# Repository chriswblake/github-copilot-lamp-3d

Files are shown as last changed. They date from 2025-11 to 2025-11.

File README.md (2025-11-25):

# GitHub Copilot Lamp 3D

Various lamp parts on a table

A fun and playful lamp to match the energy of GitHub Copilot. It's 3D printable and fairly easy to assemble!

- WiFi Connected
- Powered by [WLED](https://kno.wled.ge/)
- Compatibile with [Home Assistant](https://www.home-assistant.io/)

#### Other Fun GitHub Lamps

- [Copilot Lamp (2D)](https://github.com/chriswblake/github-copilot-lamp)
- [Octolamp](https://github.com/martinwoodward/octolamp)

## Build your own 🤓

That's cool and all, but how do I make one?!  
Check out the [build your own](docs/build-your-own.md) page for a step-by-step guide. 🧑‍🚀

## How to Use

If you received your lamp prebuilt, is has already been configured and is ready to use. Simply plug it in with a USB cable and power brick with at least 1 amp. The lamp will turn on with an "rainbow" like green effect.

### Connect with the App

1. Ensure you are on the same WiFi network.

2. Download the WLED app.
   - [iOS App](https://apps.apple.com/us/app/wled/id1475695033)
   - [Android App](https://play.google.com/store/apps/details?id=com.aircoookie.WLED)
   - The lamp can also be accessed with web browser by navigating to http://copilot-lamp-3d.local.
3. Open the app and the lamp should automatically be discovered.

### Predefined Segments, Presets, and Playlists

There are 5 predefined segments for the face, eyes, and goggles. There are also various example presets that use them to easily adjust the look of Copilot.

Below are some examples of changing the eye color, eye position, and applying animations to the face.

<div>
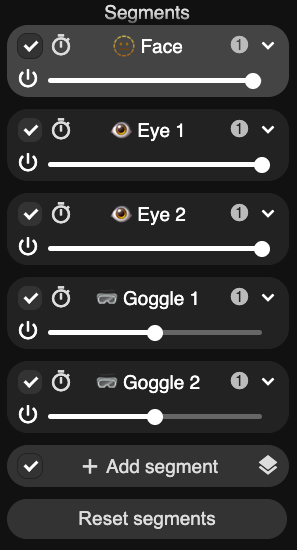
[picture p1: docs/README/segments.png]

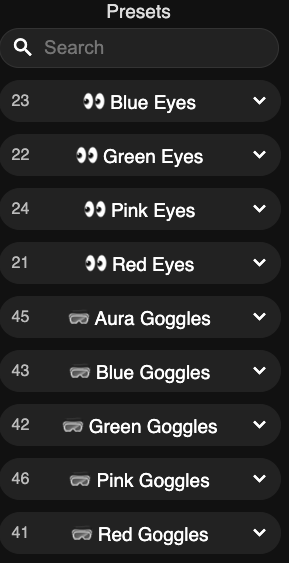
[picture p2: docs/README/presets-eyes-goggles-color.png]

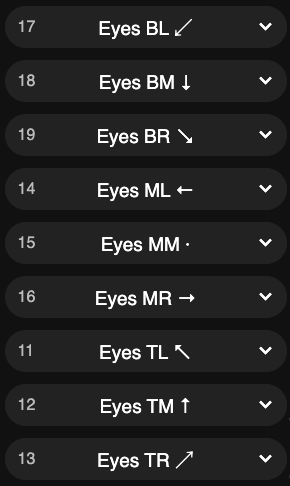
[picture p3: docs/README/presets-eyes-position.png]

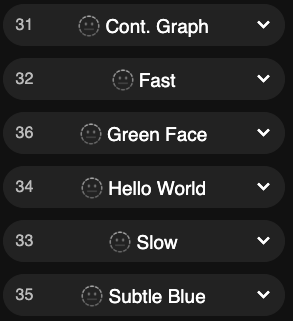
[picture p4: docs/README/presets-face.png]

</div>

> [!TIP]
> You can also do scrolling text! Check out the "Hello World" example.

### Connect to WiFi

Want full control over your lamp? Connect it to your WiFi network! (2.4ghz only)
If not connected to an existing wifi, it will broadcast a tempory wifi network for setup.

1. On your phone or computer, search for the wifi network `copilot-lamp-3d` and connect to it.
   - Default password is `copilot-lamp-3d` or `wled1234`.
1. Wait a moment and a temporary login-style web browser will appear. If no browser appears, open a web browser navigate to http://copilot-lamp-3d.local.
1. In the top right, click the **Config** gear icon to open the settings menu.
1. Select **WiFi Setup**.
1. Enter you home's wifi name and password. Click **Save & Connect**. Wait a moment for the lamp to restart.
1. Reconnect your phone or computer to your home wifi.

<div>
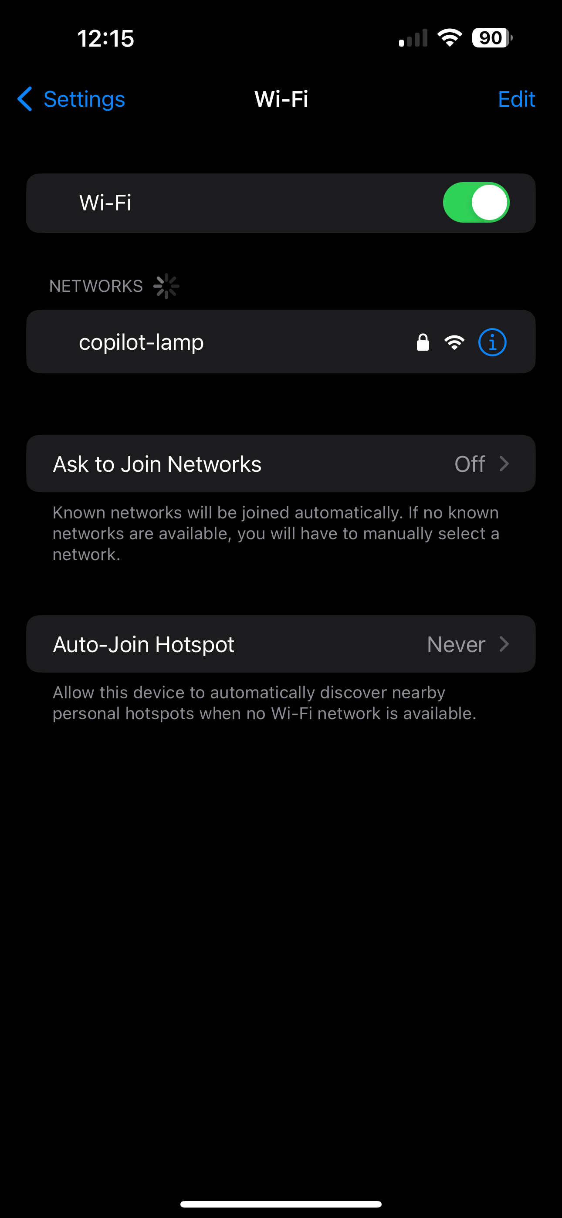
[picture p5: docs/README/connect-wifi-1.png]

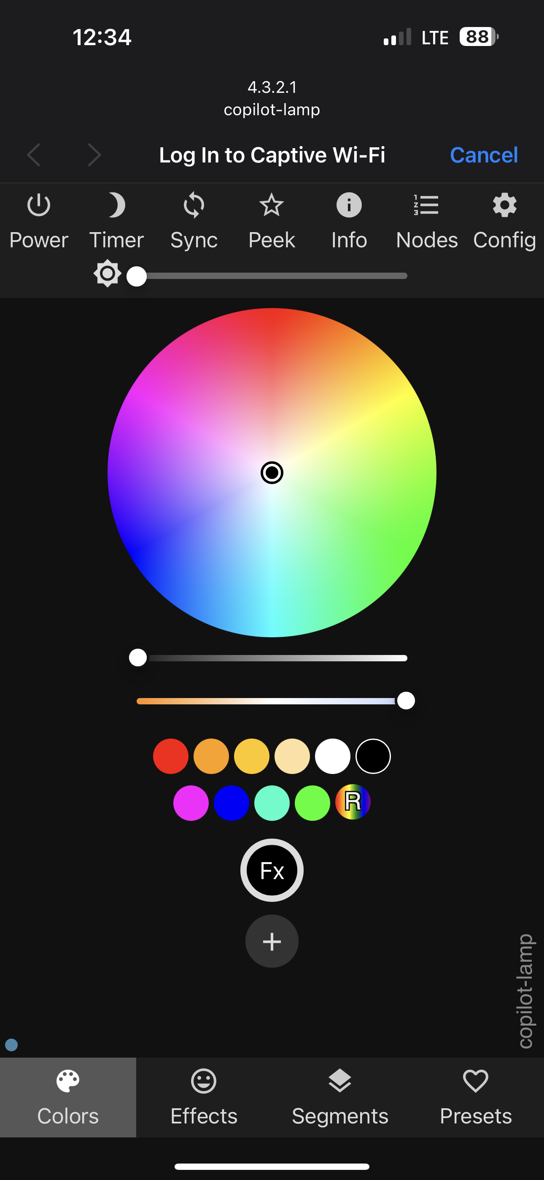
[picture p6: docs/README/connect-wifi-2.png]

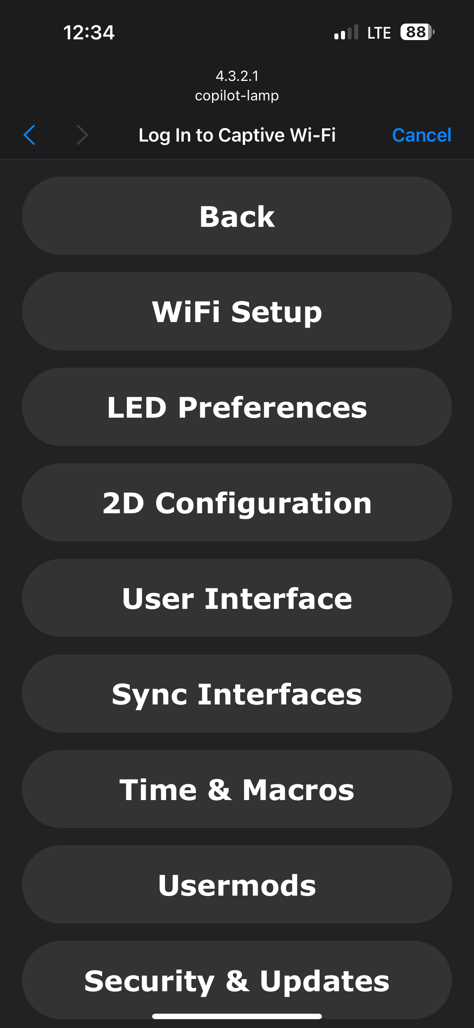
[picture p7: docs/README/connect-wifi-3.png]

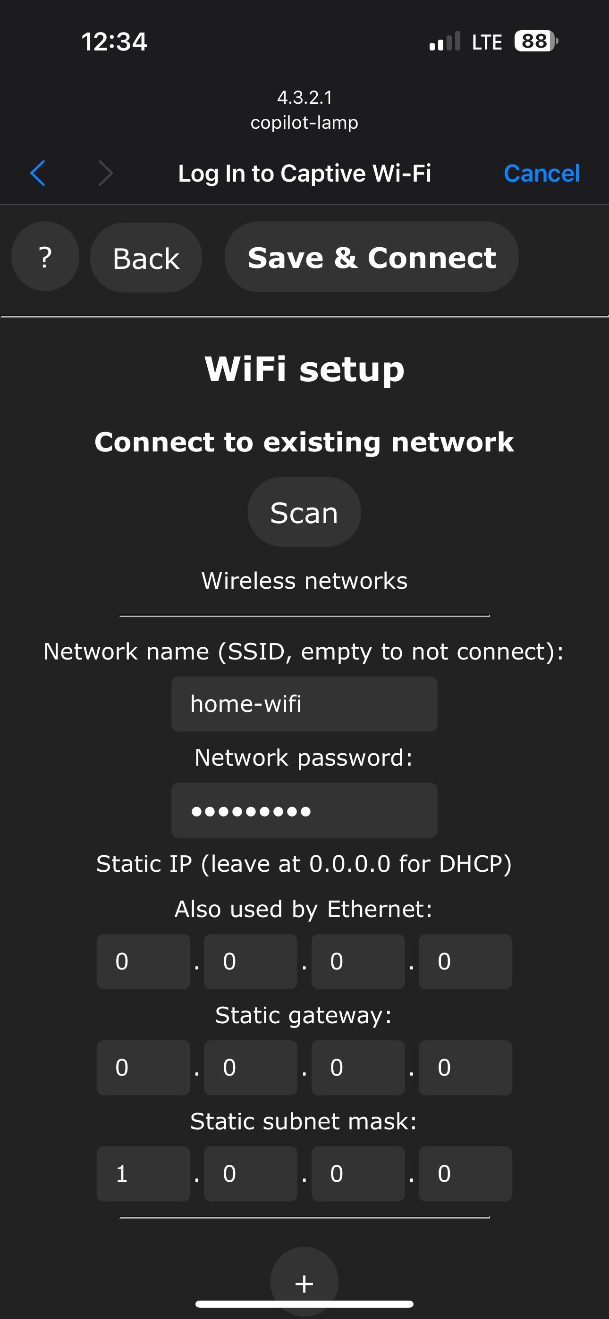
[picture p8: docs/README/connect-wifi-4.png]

</div>

### Example Animations

<table>
<tr>
<td>
    anim-1
</td>
<td>
    anim-2
</td>
<td>
    anim-3
</td>
<td>
    anim-4
</td>
</tr>
</table>

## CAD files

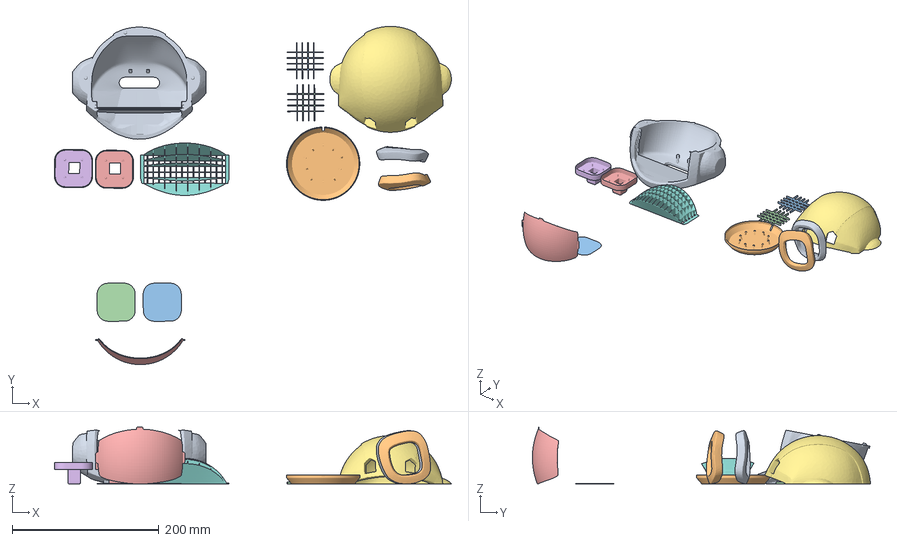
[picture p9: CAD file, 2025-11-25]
models/copilot-lamp-3d.3mf
541.5 x 461.3 x 77.7 mm
goggle 2.stl
goggle 1.stl
goggle-lens.stl x 2
goggle-holder.stl x 2
helmet-top.stl
led-guide.stl
helmet-bottom.stl
thruster-usb.stl
goggle-led-guide.stl x 2
face-panel.stl

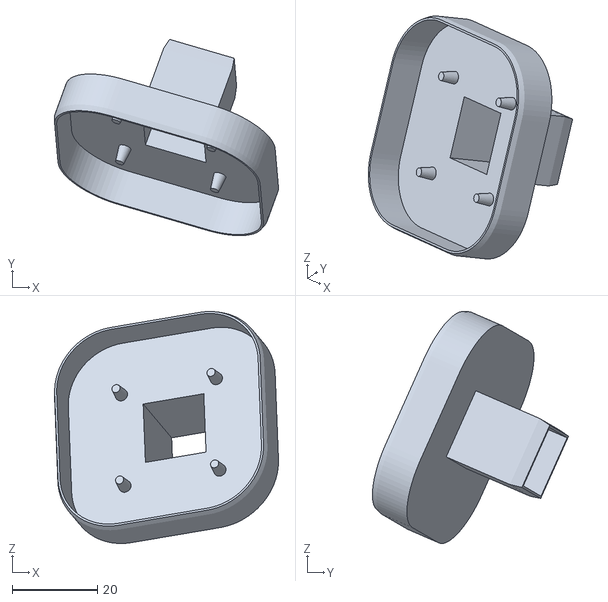
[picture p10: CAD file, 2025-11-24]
models/goggle-holder.stl
52.5 x 46.0 x 54.4

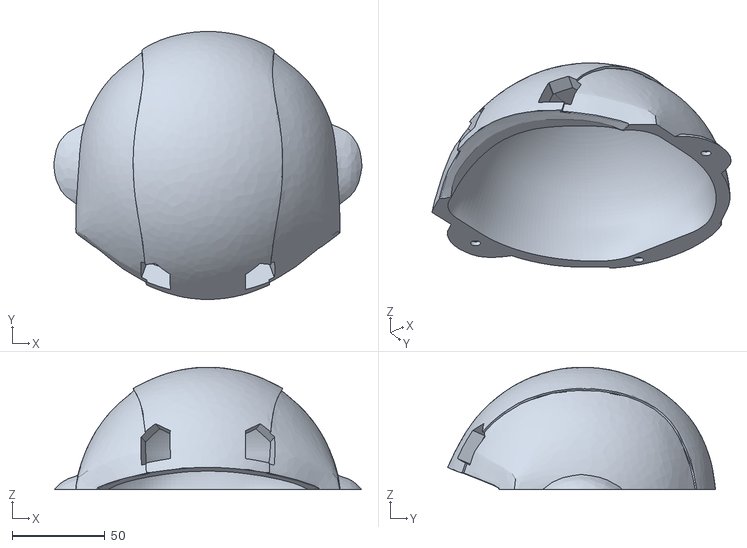
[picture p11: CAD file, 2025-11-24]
models/helmet-top.stl
166.0 x 144.4 x 66.0

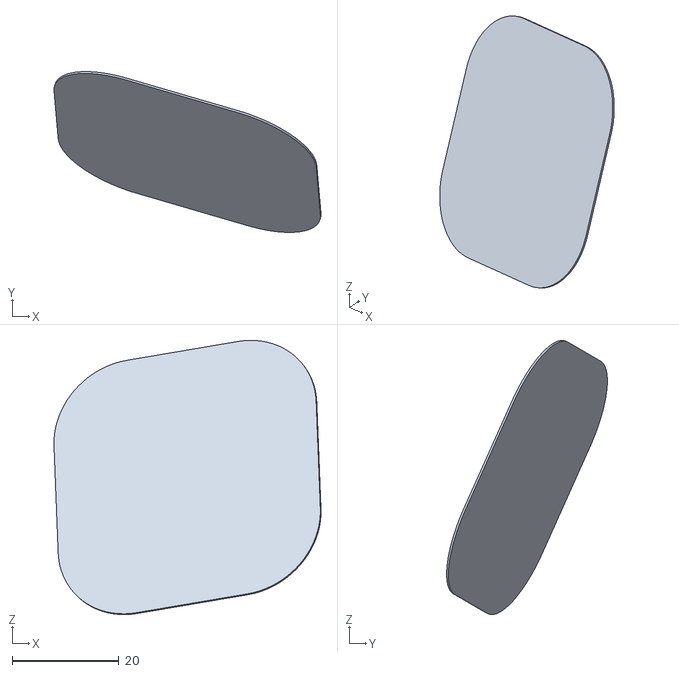
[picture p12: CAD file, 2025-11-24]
models/goggle-lens.stl
50.1 x 30.2 x 51.5

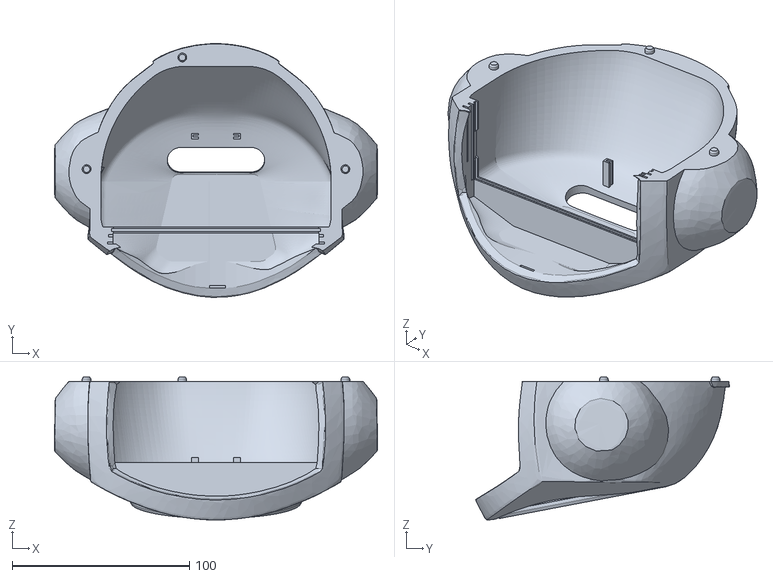
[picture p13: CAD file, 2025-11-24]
models/helmet-bottom.stl
182.2 x 143.1 x 80.6

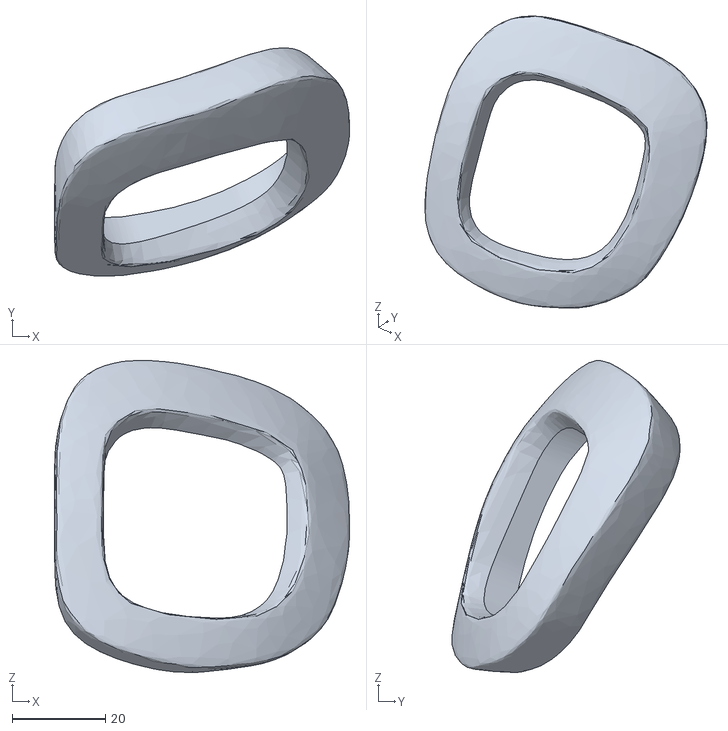
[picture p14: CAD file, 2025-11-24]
models/goggle-frame-2.stl
63.3 x 48.9 x 66.9

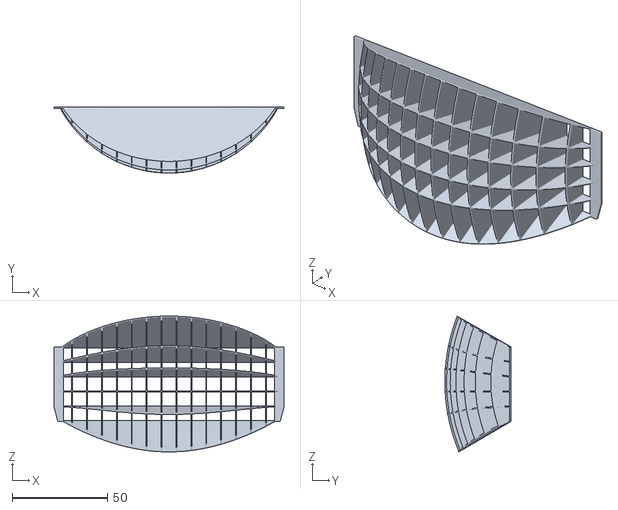
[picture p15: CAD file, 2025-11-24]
models/face-led-guide.stl
121.0 x 34.9 x 71.5

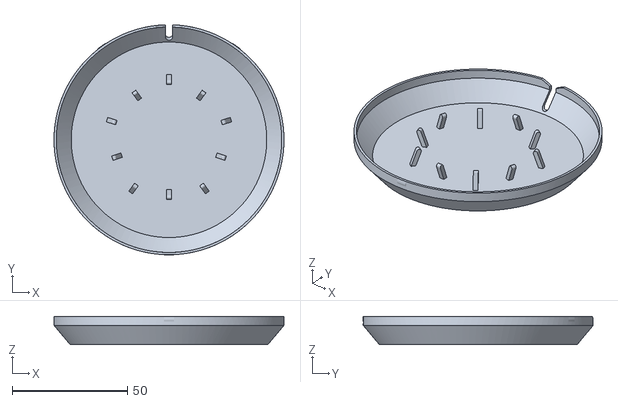
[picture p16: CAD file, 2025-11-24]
models/thruster-usb.stl
100.0 x 100.2 x 12.4

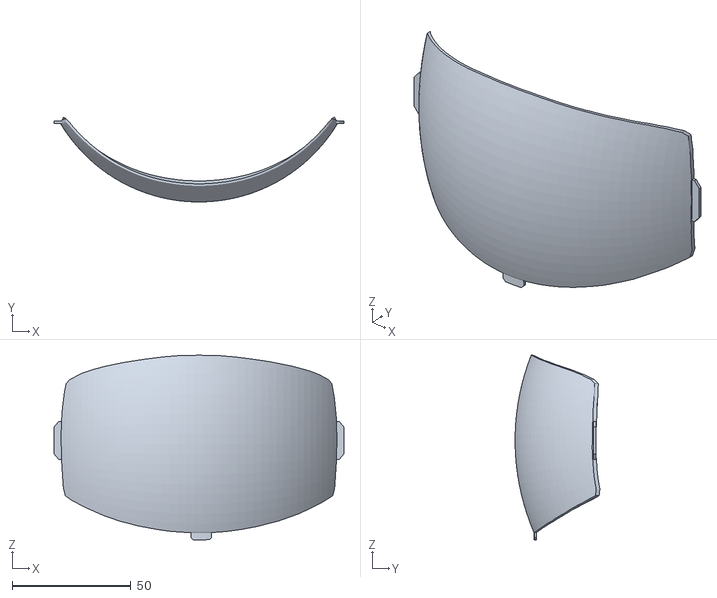
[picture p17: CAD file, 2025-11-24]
models/face-panel.stl
122.0 x 35.7 x 77.7

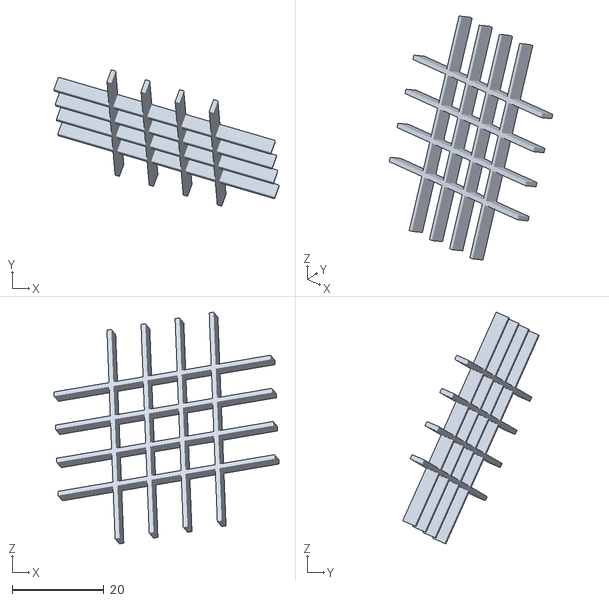
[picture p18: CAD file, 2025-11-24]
models/goggle-led-guide.stl
48.9 x 29.7 x 50.4

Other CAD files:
models/goggle-frame-1.stl

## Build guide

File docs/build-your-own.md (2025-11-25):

# Guide: Build Your Own

The copilot lamp is fairly easy to assemble with a bit of soldering. The hardest part is patiently waiting for all the parts to print! 😉

In short, it is a few 3D printed parts, a microcontroller, some LEDs and a few wires to connect it all together.

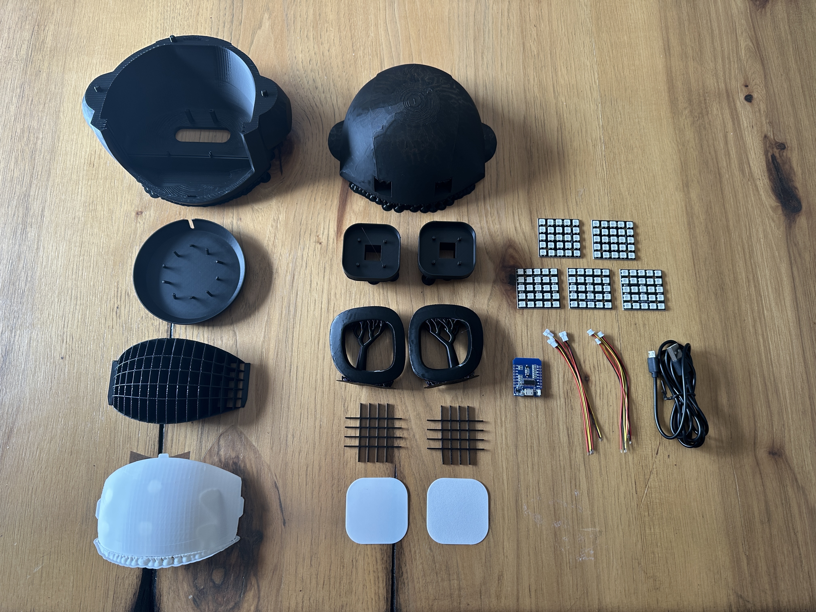
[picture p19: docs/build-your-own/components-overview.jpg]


## 1. Buy the materials

### Materials

- Black PLA Filament [[US]](https://us.store.bambulab.com/products/pla-basic-filament?variant=41078274654344)
- White PLA Filament [[US]](https://us.store.bambulab.com/products/pla-basic-filament?variant=41078274687112)
- (5 Qty) WS2812B Addressable LED Matrix (5x5) Panels [[US]](https://www.amazon.com/dp/B0FLX51BXZ)
- ESP8266 Microcontroller micro-USB + WiFi [[US]](https://www.amazon.com/dp/B081PX9YFV)
- (3 Qty) Micro JST Cable Sets [[US]](https://www.amazon.com/dp/B07DL4FNTF)
- Long micro-USB cable. [[US]](https://www.amazon.com/dp/B0CGDPS336)

> [!TIP]
> You can also use USB-C. I personally do micro-USB because the board and power cables are cheaper.

### Tools

- Soldering Iron + Solder
- 3D Printer (min 200x200 print area)
- Pliers

> [!TIP]
> Don't have a 3D printer? Check if your local library has a makerspace.  
> They might be able to print the parts for you! 🤩

## 2. Print the parts

The model (`.stl`) files for all of the printable parts are in the `/models` folder.

The `copilot-lamp-3d.3mf` file is already configured with best orientation, support settings, and suggested layer heights.

> [!IMPORTANT]
> Supports are required for several parts.
> Please check your slicer results before printing.

| Image | Part | Description |
| --- | --- | --- |
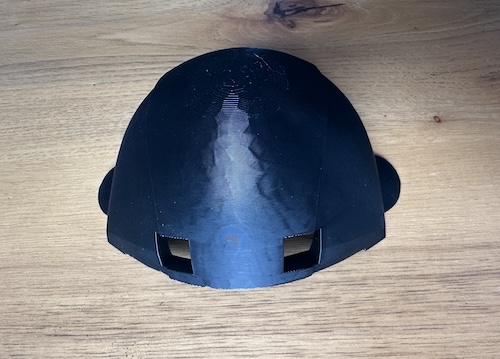
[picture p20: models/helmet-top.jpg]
|  | Helmet Top | ??? |
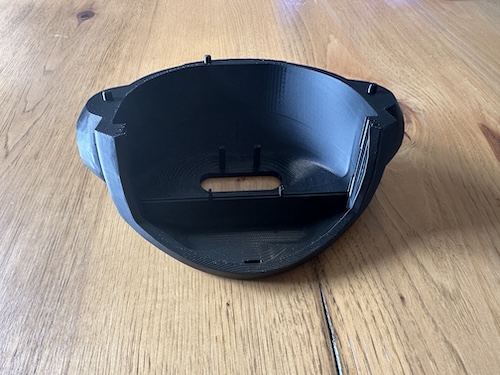
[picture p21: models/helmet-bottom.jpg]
|  | Helmet Bottom | Holds the microcontroller, LEDs, and face panel. |
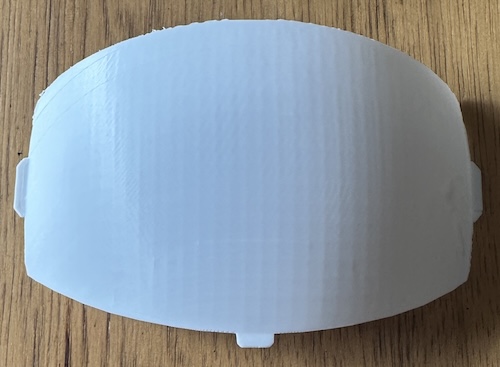
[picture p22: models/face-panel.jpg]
|  | Face Panel | Semitransparent face shield for the LED to glow through. |
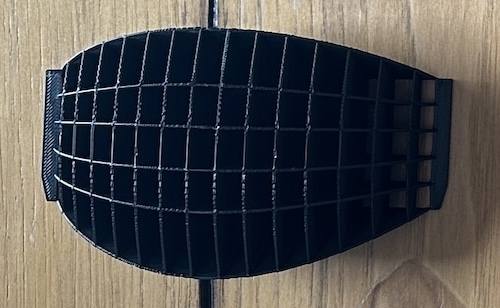
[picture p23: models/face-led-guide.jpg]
|  | Face LED Guide | Maps the light from the LEDs to pixels on the face panel. |
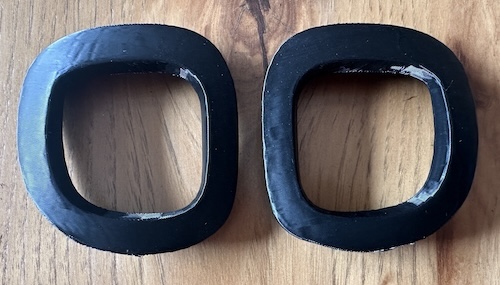
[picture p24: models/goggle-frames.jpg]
|  | Goggle Frames 1 & 2 | Snaps onto the Goggle holder to give it the correct shape. |
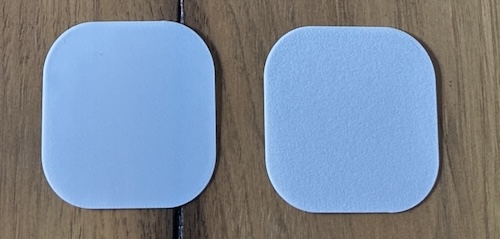
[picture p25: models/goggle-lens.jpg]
|  | Goggle Lens 1 & 2 | Diffuses the LEDs. |
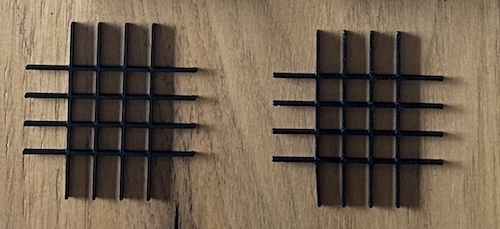
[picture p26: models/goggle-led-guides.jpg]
|  | Goggle LED Guides 1 & 2 | Maps the light from the LEDs to pixels on the face panel. |
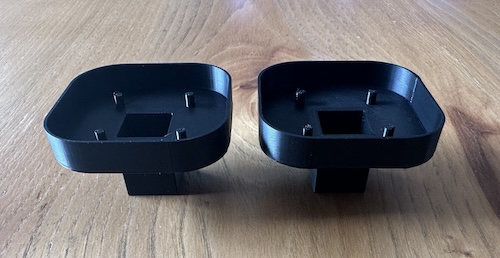
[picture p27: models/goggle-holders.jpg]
|  | Goggle Holders | Contains the LEDs for a single Goggle and mounts to the helmet top. |
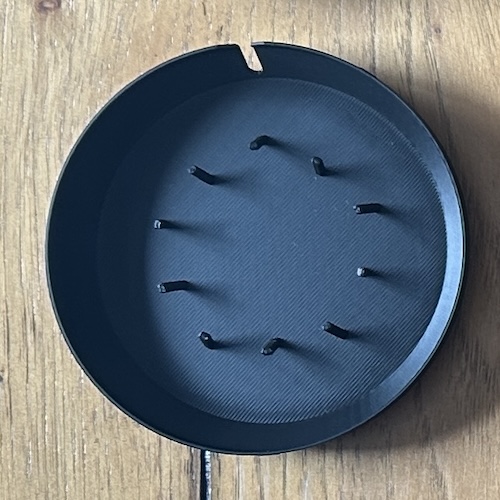
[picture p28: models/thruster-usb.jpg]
|  | Thruster (USB) | Space for securing the USB cable or creating an alternative base. |

## 3. Prepare the Microcontroller

Let's install the software that will control our LEDs,
and configure the regions for easily changing the face, eyes, and googles.

### 3.1 Install WLED

1. Connect the microcontroller to your computer using a USB cable.

1. Open a web browser and navigate to the [WLED install page](https://install.wled.me/).

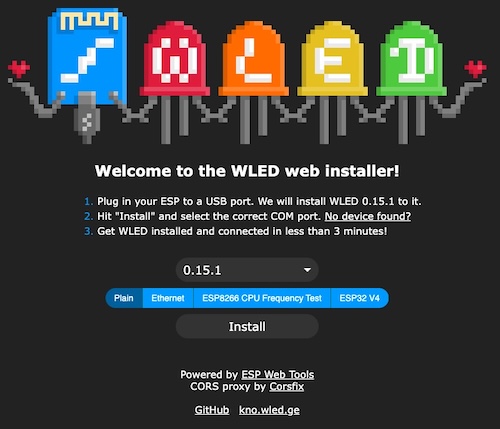
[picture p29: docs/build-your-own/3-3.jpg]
   

1. In the drop down, ensure version `0.15.x` is selected.

1. Click the **Install** button and a window will appear with a list of devices.

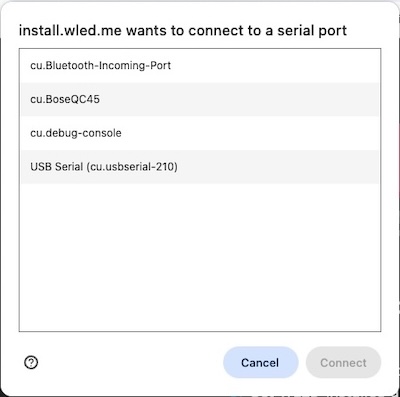
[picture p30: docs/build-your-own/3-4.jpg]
   

1. Select the **USB Serial** device.

   - If no device is appearing, follow WLEDs tips about installing drivers.
   - Tip: Newer Macs seem to not include the driver by default anymore.

1. Follow the instructions and wait a few minutes to install.

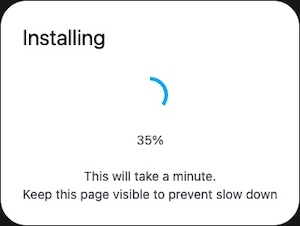
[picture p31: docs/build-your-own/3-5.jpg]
   

1. When the **Configure Wi-Fi** page appears, enter your network's details.

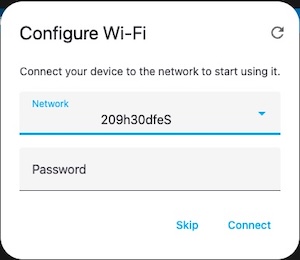
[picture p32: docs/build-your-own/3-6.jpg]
   

1. When the install is finished, click the **Visit Device** button.

### 3.2 Configure WLED

Let's upload a configuration for the device's LED orientation, and then presets to assign regions with names like "Face", "Eye", and "Goggle".

1. On the device's main page, in the top right, click the **Config** button.

2. Scroll to the bottom and select **Security and Updates**.

3. Find the **Backup & Restore** section.

4. For the **Restore Presets** option. Upload the following file.

   File: [`/wled/presets_playlists.json`](../wled/presets_playlists.json)

   This will install the following:

   - Segments defininig the face, eyes, and goggles.
   - Presets with example face animations.
   - Presets with example goggle animations.
   - Presets with example eye colors and locations.
   - A playlist to apply a combination of presets on boot.

5. For the **Restore Configuration** option, upload the following file.

   File: [`/wled/configuration.json`](../wled/configuration.json)

   This will install following:

   - Set the device to use 124 LEDs and max 1 amp power.
   - Assign a 2D layout for the 5 LED matrix panels.
   - Configure a timer option to turn on the lamp at 9am and off at 5pm. - Enable the option to broadcast a WiFi network named `copilot-lamp-3d`, if no WiFi is found.
   - Configure a timer option to turn on the lamp at 9am and off at 5pm.
   - Set the device's network name to `copilot-lamp-3d`.

### 3.3 Attach the LED cable

1. Attach a **socket-style** JST cable to the microcontroller.

   - Red Wire: `5V` (power)
   - Black Wire: `G` (ground)
   - Yellow Wire: `D4` (digital)

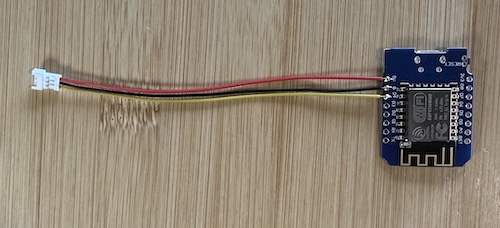
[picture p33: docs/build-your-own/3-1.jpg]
   
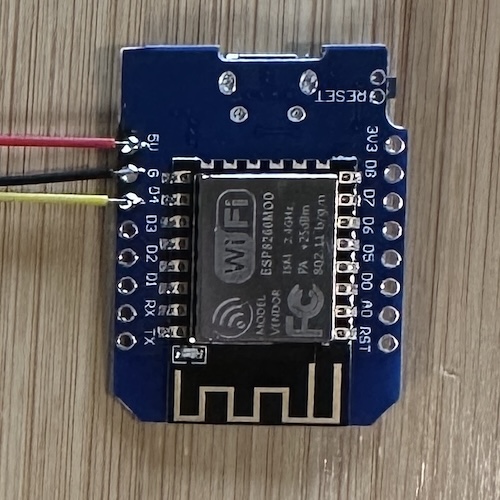
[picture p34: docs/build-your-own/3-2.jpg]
   

## 4. Prepare the Face LEDs

Let's connect 3 LED matrix boards together. This will be the lights for Copilot's face.

1. Align 3 of the matrix boards with the text facing the same direction. Tape them together.

   > ⚠️ **Warning:** The Orientation must be correct.
   > `DIN` will align with `DOUT` on the board next to it.

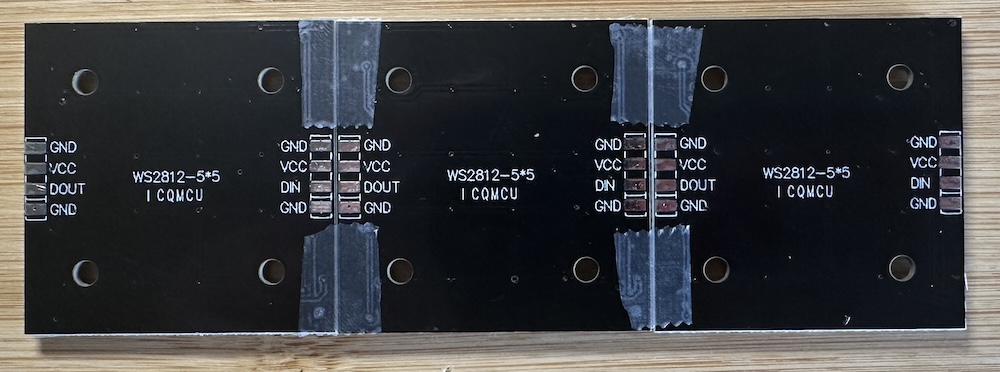
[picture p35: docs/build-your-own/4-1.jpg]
   

2. Link the boards by soldering them together. Only 1 `GND` is necessary per connection.

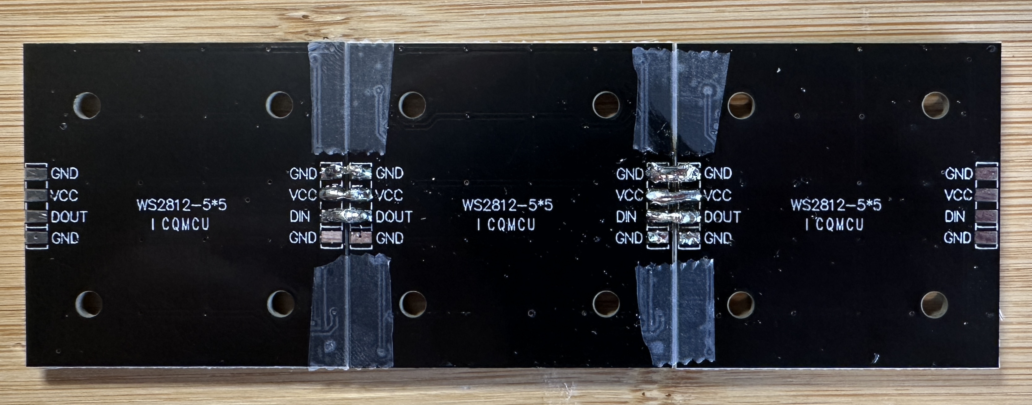
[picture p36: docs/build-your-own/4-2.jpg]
   

   > 🪧 **Note:** Soldering can be difficult, especially across a gap. Just be patient and keep trying. 🧐

3. Attach the JST cables.

   - Make sure the cables run toward the middle, not outwards.
   - Make sure the cables do not extend past the edge of the panel. Otherwise, it will not slide into the mounting slot.
   - Pay attention to the cable location and type.

     - `DIN` (right side) uses a plug-style cable.
     - `DOUT` (left side) uses a socket-style cable.

   - Pin mapping
     - Red Wire: `VCC` (power)
     - Black Wire: `GND` (ground)
     - Yellow Wire: `DIN` or `DOUT` (digital)

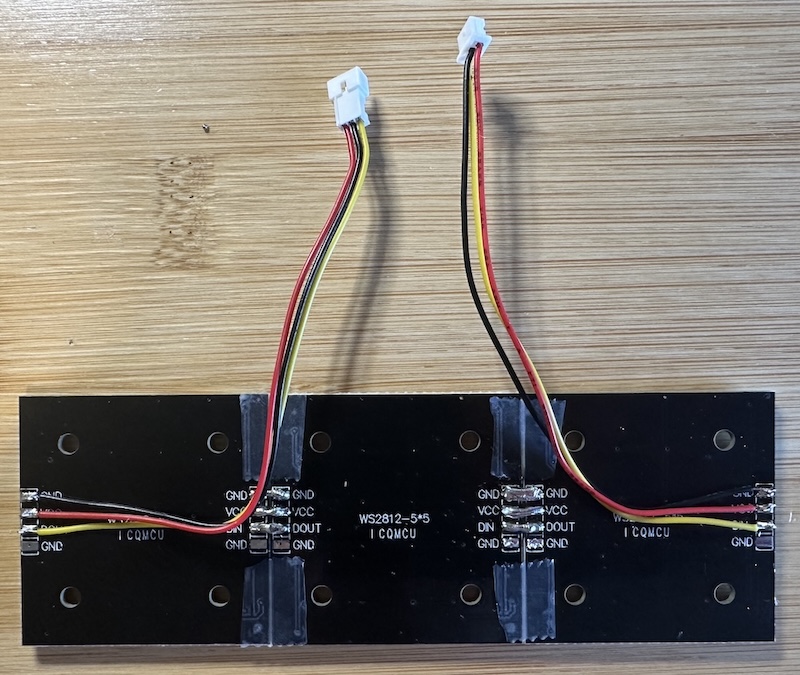
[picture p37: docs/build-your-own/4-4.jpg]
   

## 5. Prepare the Goggles LEDs

Let's prepare 2 LED matrix boards for Copilot's goggles.

- One has both a plug-style cable and socket-style cable.
- One has only a plug-style cable.

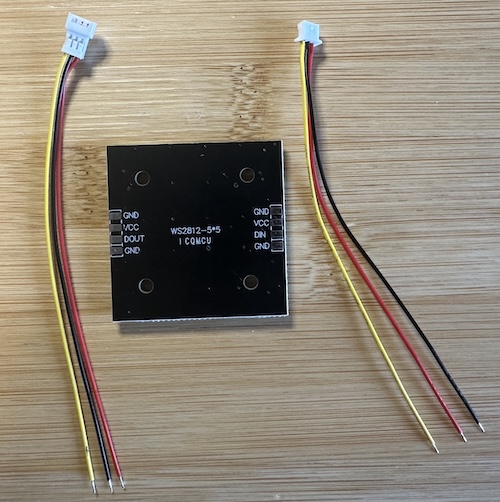
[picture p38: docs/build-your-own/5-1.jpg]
   
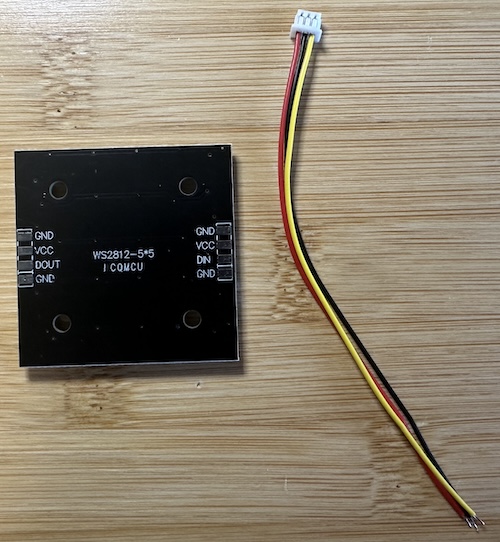
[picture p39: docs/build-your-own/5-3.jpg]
   

1. With one LED matrix, attach both a **socket-style** and **plug-style** cable.

   - Make sure the cables run toward the middle, not outwards.
   - Pay attention to the cable location and type.

     - `DIN` (right side) uses a plug-style cable.
     - `DOUT` (left side) uses a socket-style cable.

   - Pin mapping
     - Red Wire: `VCC` (power)
     - Black Wire: `GND` (ground)
     - Yellow Wire: `DIN` or `DOUT` (digital)

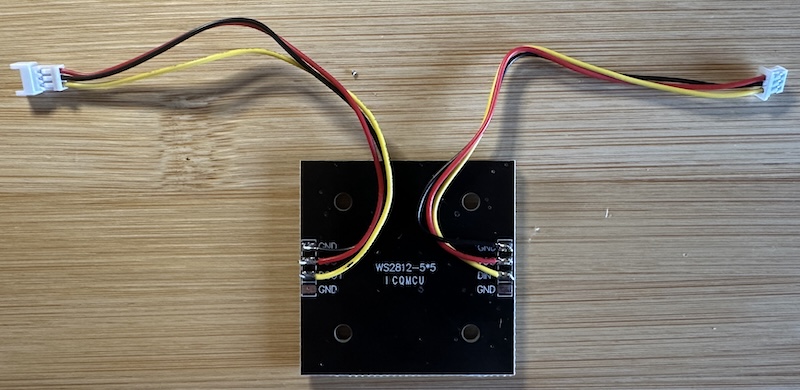
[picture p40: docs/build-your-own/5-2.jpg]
   

1. With another LED matrix, attach a **plug-style** cable.

   - Make sure the cables run toward the middle, not outwards.
   - Pin mapping
     - Red Wire: `VCC` (power)
     - Black Wire: `GND` (ground)
     - Yellow Wire: `DIN` (digital)

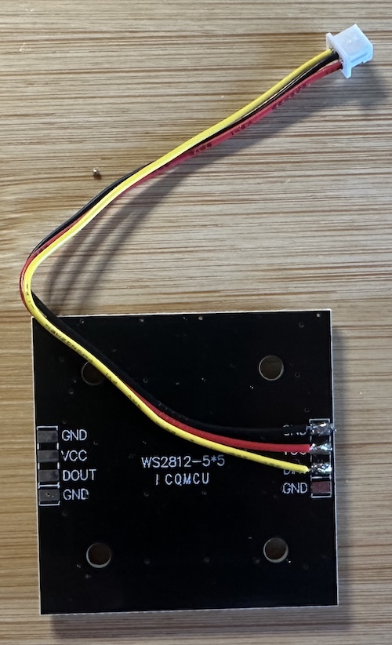
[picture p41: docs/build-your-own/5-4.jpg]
   

## 6. Electronics Check

1. Connect the microcontroller, Face LED panel, and 2 Goggle LED panels together.

1. Apply power to the microcontroller by plugging in via USB.

1. Verify the lights appear. Colors do not matter.

   Examples:

   WLED's default if no default provided.
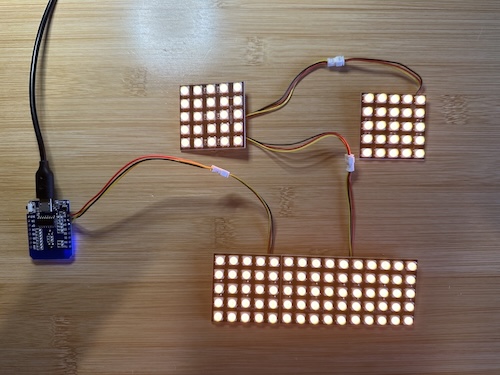
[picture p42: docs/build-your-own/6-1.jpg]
   

   Default set to a preset with random color animation.
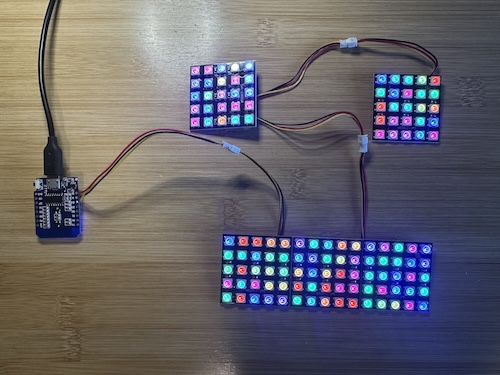
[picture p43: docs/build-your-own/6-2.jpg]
   

## 7. Face Install

1. Collect the following parts:

   - Helmet Bottom
   - Face LED Guide
   - Face LED LED panel
   - Microcontroller

2. Slide the Face LED panel into the groove 1 (furthest inward).

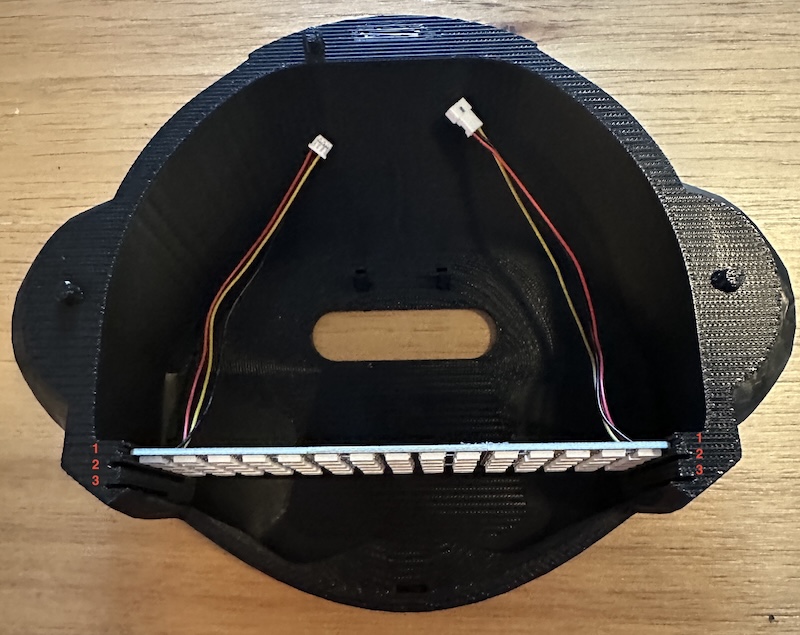
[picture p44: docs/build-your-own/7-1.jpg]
   

3. Slide the LED Guide into the groove 2 (middle option).

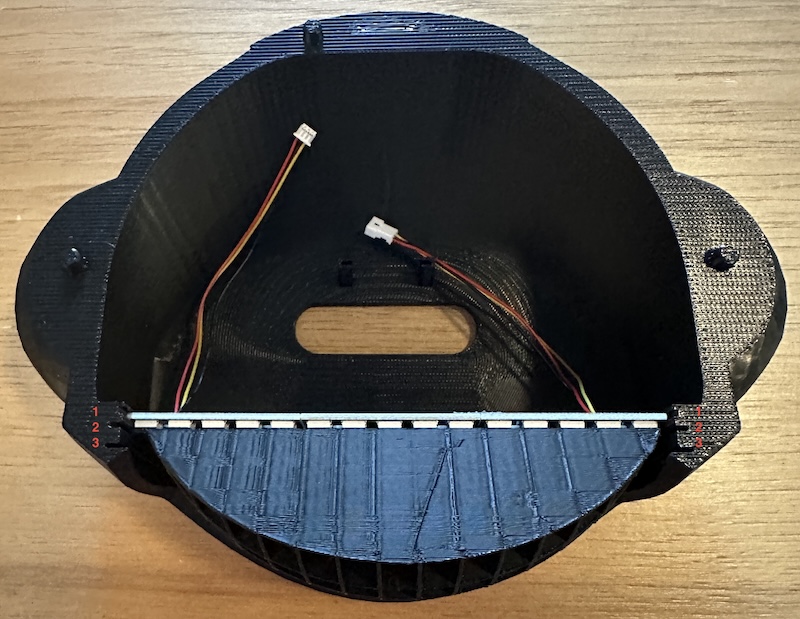
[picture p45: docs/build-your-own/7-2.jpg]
   

4. Coming from the front, slightly bend the Face panel and wrap it around the LED Guide. to insert it.

   - The side mount flaps will extend into groove 3 (furthest outward).
   - The bottom mount fap will slide downward into a groove in the chin area.

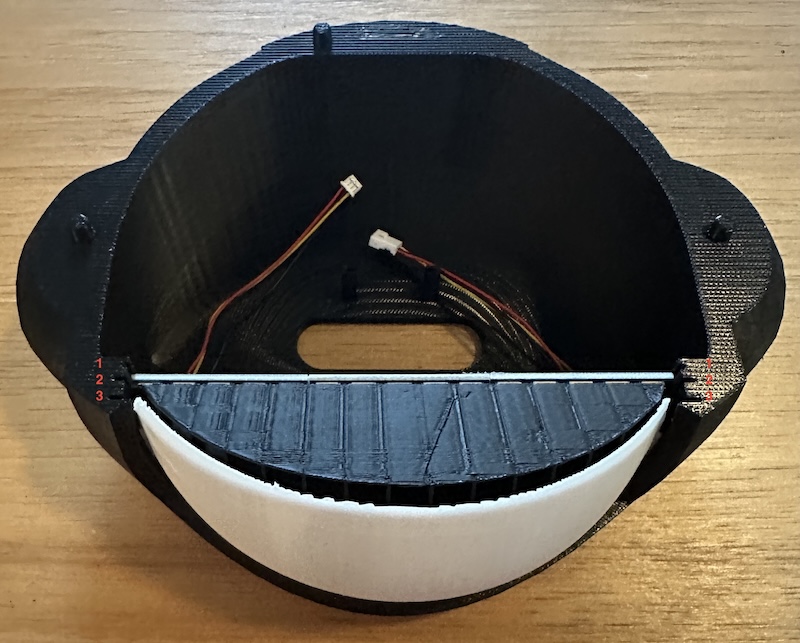
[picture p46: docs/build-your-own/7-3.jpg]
   

## 8. Goggles Preparation

1. Collect the following parts:

   - Goggle Frames 1 & 2
   - Goggle Holders 1 & 2
   - Google Lens 1 & 2
   - Goggle LED Guides 1 & 2
   - Both single LED Matrix panels.

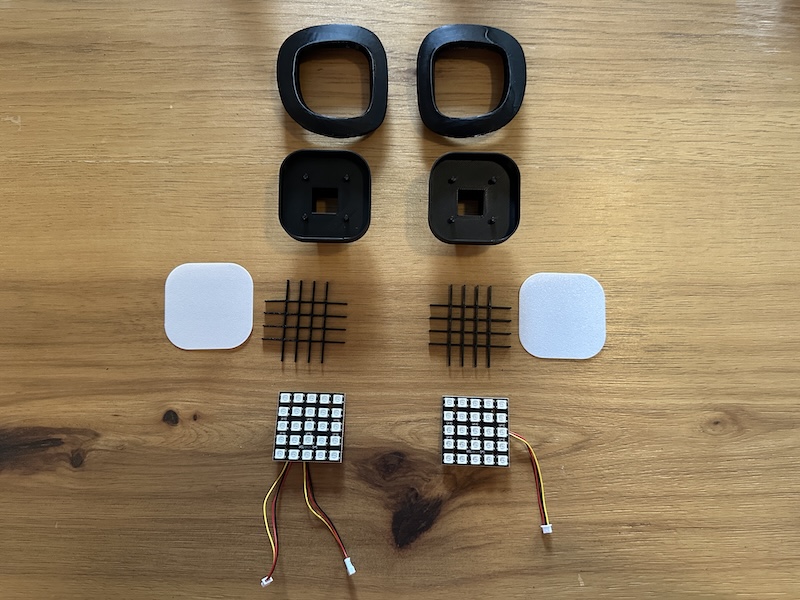
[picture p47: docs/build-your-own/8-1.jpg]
   

2. Slide the **double-cabled** LED panel's cables through the hole of a Goggle Holder. Align the pins and push down to attach the LED panel.

   - It will hold by friction.
   - Orientation in the holder does not matter.

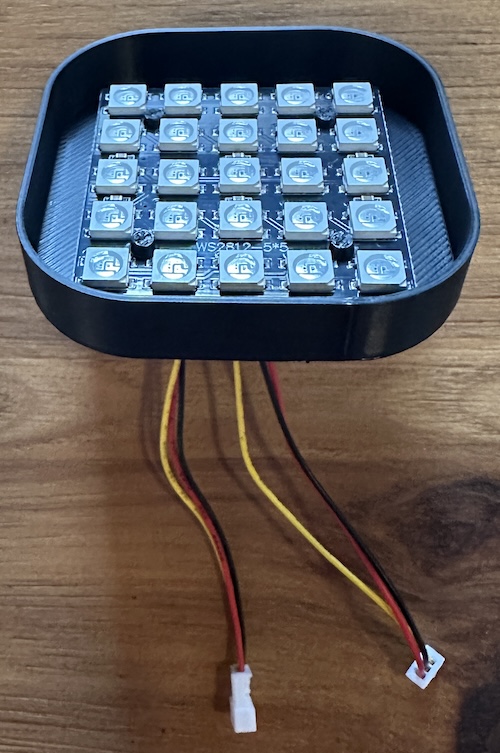
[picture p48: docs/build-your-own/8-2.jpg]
   

3. Rotate the combined unit so the text is upright, same as picture above.

4. Insert the LED Guide.

   - It will hold by friction.
   - Orientation in the holder does not matter.

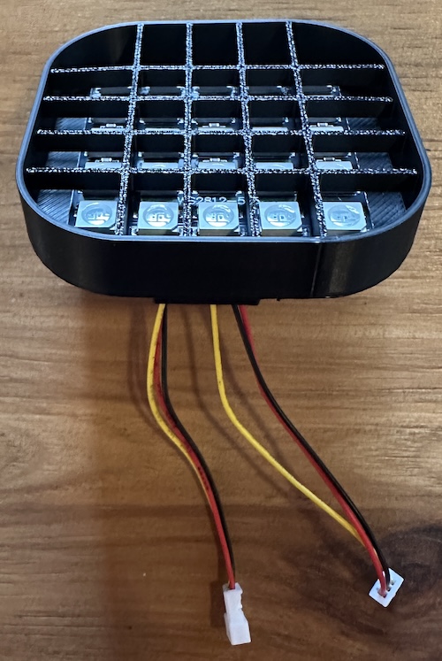
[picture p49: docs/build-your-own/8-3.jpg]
   

5. Select Goggle Frame 1 and insert a lens.

   - It will hold by friction.
   - Place the textured side facing outward.

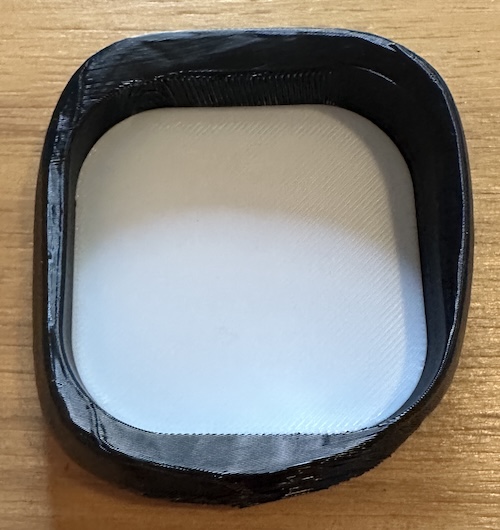
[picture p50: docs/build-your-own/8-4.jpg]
   

6. Slide the Goggle Frame over the Goggle Holder .

   - ❗️ **IMPORTANT:** Verify the text is upright.
   - ❗️ **IMPORTANT:** The straighter edge will be on the **right**.

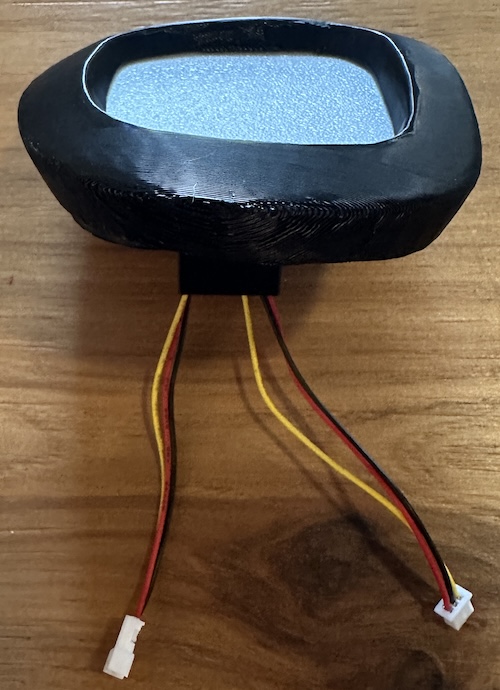
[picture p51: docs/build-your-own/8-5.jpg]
   

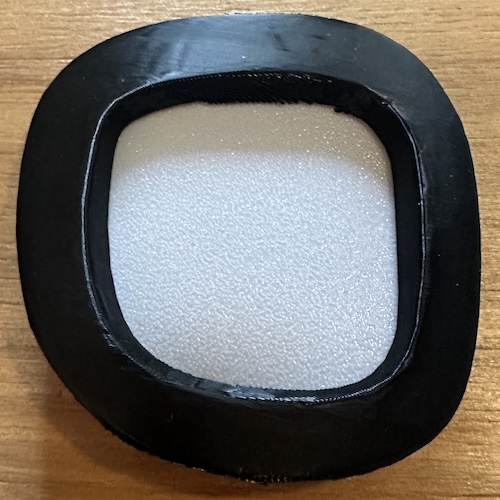
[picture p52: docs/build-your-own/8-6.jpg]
   

7. Repeat the above steps with the **single-cable** LED Panel.

   - ❗️ **IMPORTANT:** Verify the text is upright.
   - ❗️ **IMPORTANT:** The straighter edge will be on the **left**.

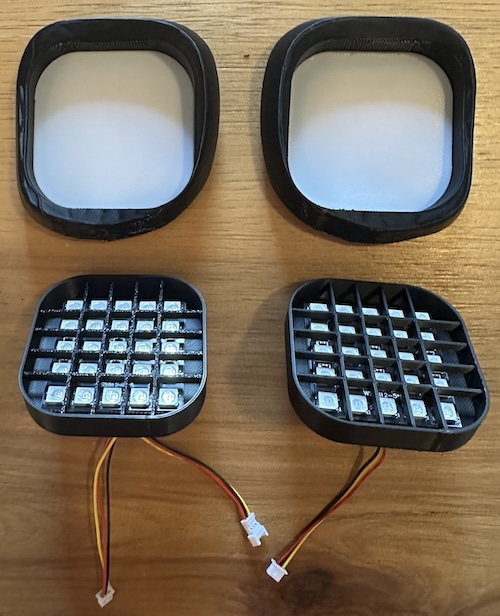
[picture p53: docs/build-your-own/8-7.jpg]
   

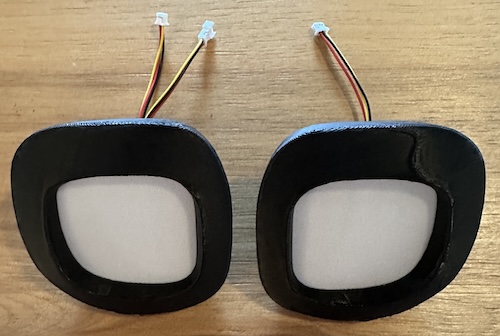
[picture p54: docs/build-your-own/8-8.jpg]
   

## 9. Goggles Install

1. Collect the following parts:

   - Top Helmet
   - Goggle 1
   - Goggle 2

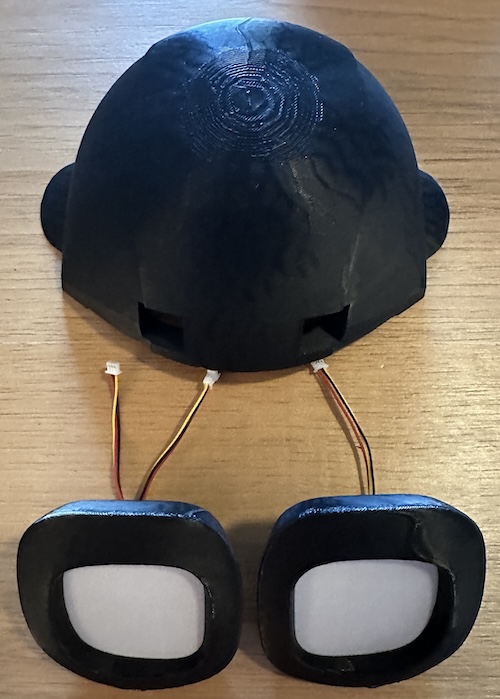
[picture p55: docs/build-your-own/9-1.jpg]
   

1. Insert Goggles 1 and 2 into the respective ports.

   - The flatter edge will be in the middle.

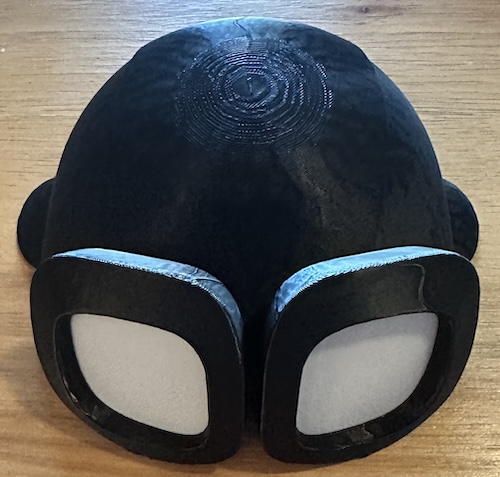
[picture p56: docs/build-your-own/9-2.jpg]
   

1. Flip the combined unit over and connect the 2 cables togther.

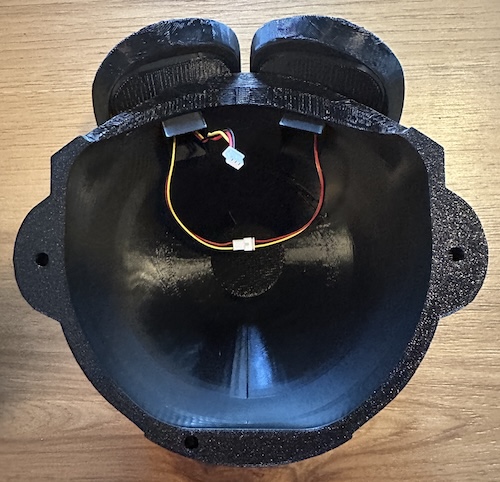
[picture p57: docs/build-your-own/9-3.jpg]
   

## 10. Microcontroller Install

Let's mount the microcontroller in the helmet and connect it to the LEDs and USB cable.

1. Slide the microcontroller into the slot in the Helmet Bottom.

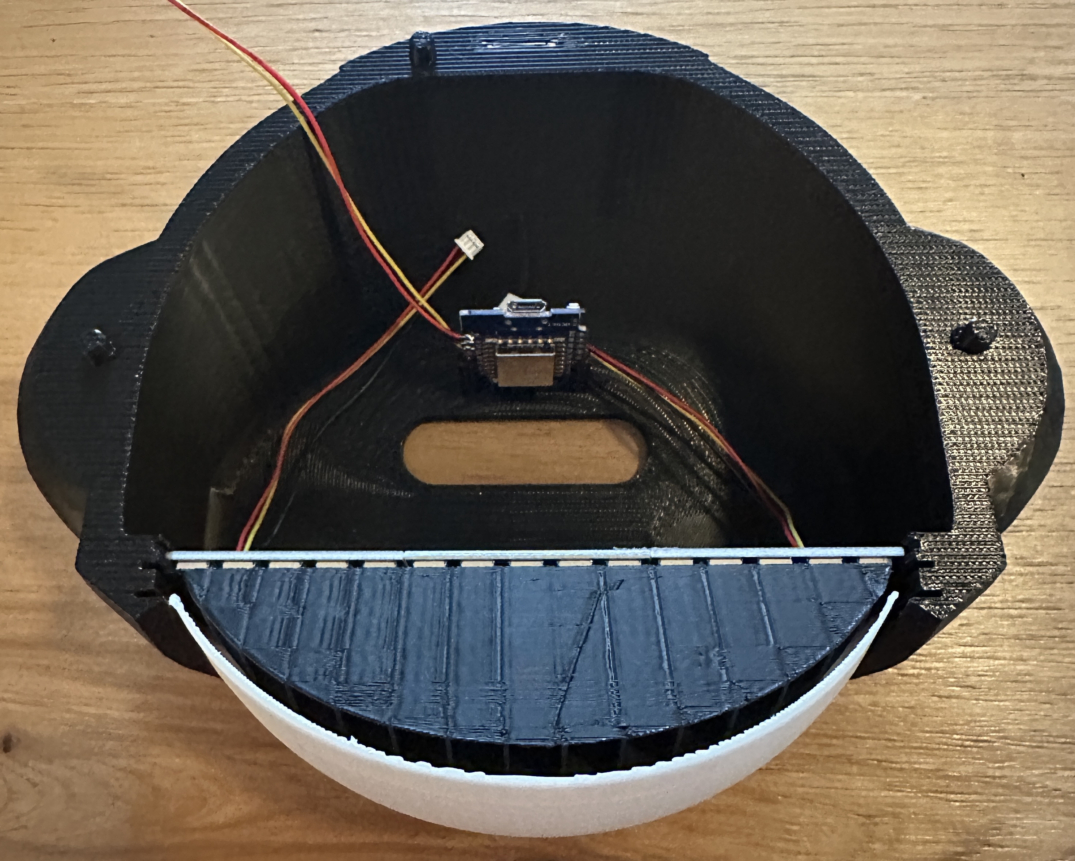
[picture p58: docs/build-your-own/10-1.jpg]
   

1. Connect the Face LED cable and Microcontroller cable.

   

1. Pass the USB cable through the lower hole and plug it into the Microcontroller.

   

## 11. Attach Helmets and Thruster

Let's combine the 2 halves and then route the USB cable through the thruster.

1. Orient the two assemblies similar to the below picture then connect the Goggle LEDs and Face LEDs.

   

2. Flip the Helmet Top assembly over onto Helmet Bottom, align the pins, and gently press downward to connect them.

   - **Tip:** Do not push it all the way down yet!

   

3. Tilt the lamp on its side.

4. In the Thruster, route the usb cable through several of the cable guides and out through the slot.

   

5. Align the round thruster with the ring/groove on the bottom of the lamp. Press it inwards for it to snap into place.

   - The bottom of the lamp and the thruster have 3 matching notches.
   - The cable will orient out of the back of Copilot.

   

## 4. Final Checks

1. Apply power and verify all lights turn on.

2. Wait a moment and verify WiFi activates.

3. Try accessing the lamp from your phone or computer.

4. Try various color animations.

5. You are finished! See the main [README](../README.md) for usage info. Plug it in and enjoy!

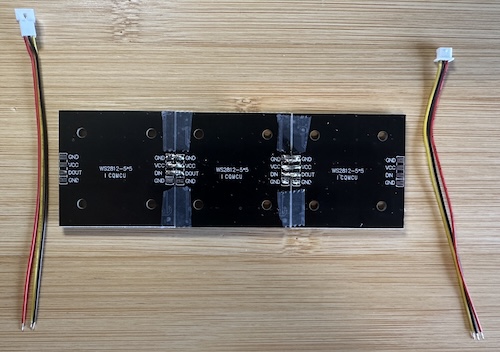
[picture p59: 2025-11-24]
docs/build-your-own/4-3.jpg

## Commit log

2025-11-12 Add section about materials to buy
2025-11-12 Add draft section about printable parts.
2025-11-12 add draft instructions for preparing LEDs and microcontroller
2025-11-12 add draft instructions for final assembly
2025-11-24 feat: add .stl models
    [face-led-guide.stl, face-panel.stl, goggle-frame-1.stl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]
2025-11-24 feat: add .3mf file
    [copilot-lamp-3d.3mf]
2025-11-24 feat: add chamfer to goggle holder to make assembly easier
    [copilot-lamp-3d.3mf, goggle-holder.stl]
2025-11-25 fix: incorrect supports on top helmet
    [copilot-lamp-3d.3mf]
